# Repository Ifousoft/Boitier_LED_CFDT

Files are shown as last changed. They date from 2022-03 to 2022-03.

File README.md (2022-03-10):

# Boitier_LED_CFDT
Boitier autonome avec une LED clignotante au passage d'une personne devant un panneau d'affichage pour inciter à lire le panneau

L'objectif est la réalisation d'un petit boitier autonome fonctionnant sur piles à accrocher sur un panneau d'affichage CFDT.
Lorsqu'une personne passe devant le panneau, le capteur de présence réveille le système, la LED clignote pour indiquer qu'une nouvelle information a été affichée. Le système se rendors automatiquement pour économiser les piles.

Le système s'arrête automatiquement et se mets en sommeil après 2 jours d'utilisation, considérant que l'information n'est plus suffisamment récente.

Dans le cas d'un nouvel affichage, il suffit d'appuyer sur le bouton et le sytème rédémarre pour 2 jours.

D'après les calculs, le boitier devrait fonctionner sur pile pendant environ 1 an. Dans le cas où la pile CR2032 pour l'horloge est usée, au démarrage du système, le LED clignotera sans s'arrêter.

Le boitier comprends un arduino pour la partie processeur, une LED, orange (forcément), un bouton de réinitialisation et un mini capteur PIR pour détecter les passages des personnes.

CFDT_Boitier

PS: ayant réalisé une première version mais sans horloge, j'ai fais cette seconde version. Le code fonctionne et le schéma électronique est OK.
Néanmoins, je n'ai pas testé la réalisation du PCB ni vérifier l'impression 3D du boitier pour valider l'assemblage de tous les composants.
N'hesitez pas à effectuer des modifications si nécessaire.

Ifousoft.

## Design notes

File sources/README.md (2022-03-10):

Sources en C++ pour le boitier LED autonome
Compilation avec Platformio

Nécessite la biliothèque
lib_deps = adafruit/RTClib@^2.0.2

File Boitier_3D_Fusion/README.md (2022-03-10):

Fichier Fusion 360 et fichier STL pour l'impression 3D des deux parties du boitier, dessous et dessus.

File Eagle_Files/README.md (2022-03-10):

Fichiers Eagle pour la conception du schéma électronique et du PCB.

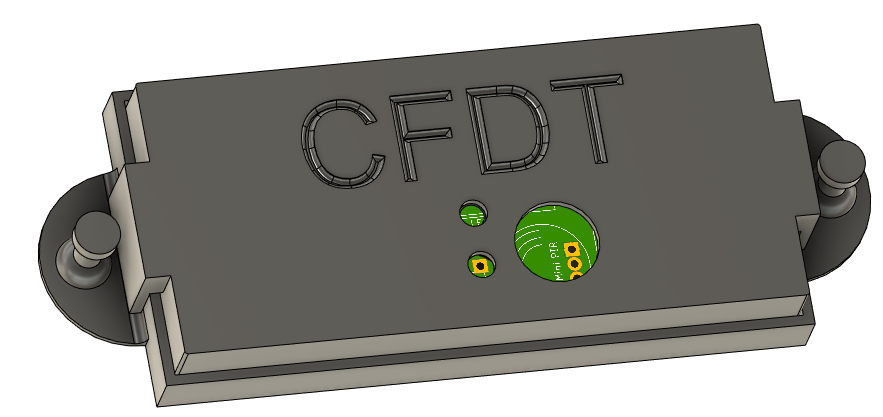
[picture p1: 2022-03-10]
Boitier_3D_Fusion/CFDT_Boitier.png

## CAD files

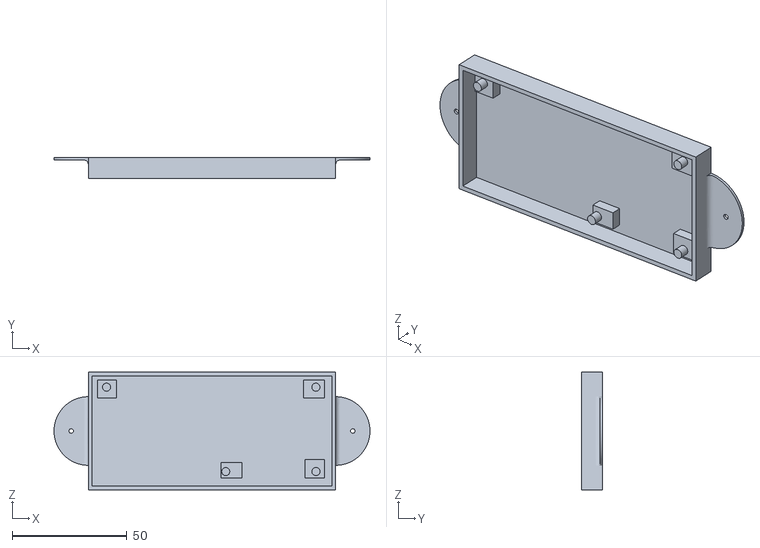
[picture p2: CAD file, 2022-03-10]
Boitier_3D_Fusion/Dessous_CFDT.stl
138.0 x 9.00 x 51.5

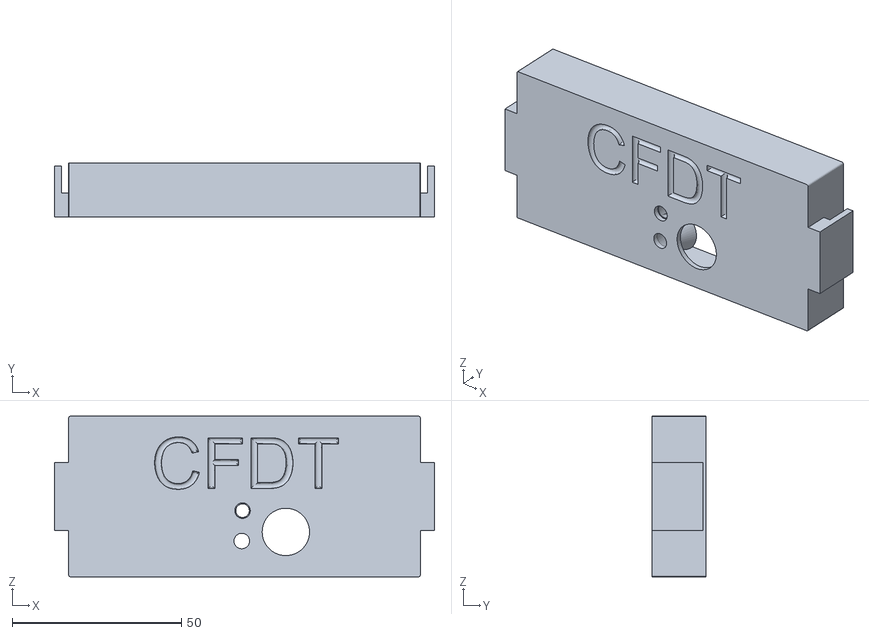
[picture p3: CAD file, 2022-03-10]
Boitier_3D_Fusion/Dessus_CFDT.stl
112.4 x 16.1 x 47.5

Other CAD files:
Boitier_3D_Fusion/Boitier_CFDT v27.f3d

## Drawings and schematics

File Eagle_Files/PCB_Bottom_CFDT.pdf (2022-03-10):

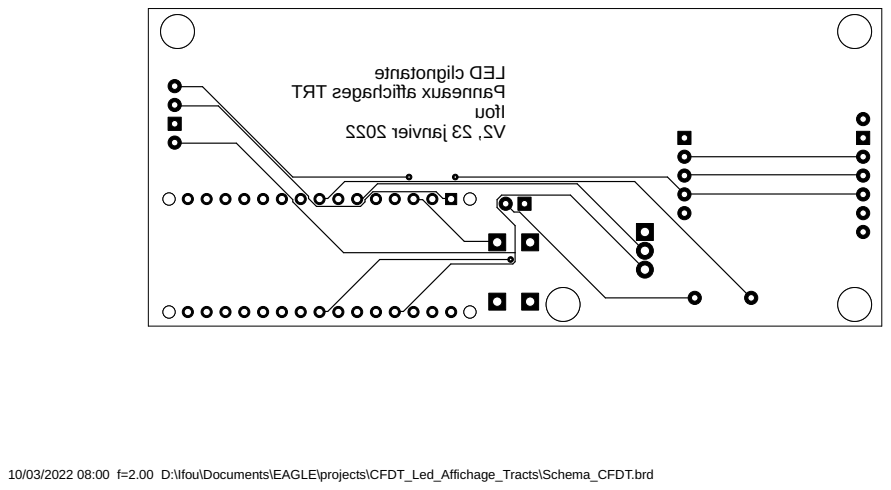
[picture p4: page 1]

et nat ongil c DEL

10/03/2022 08:00 f=2.00 D:\Ifou\Documents\EAGLE\projects\CFDT_Led_Affichage_Tracts\Schema_CFDT.brd

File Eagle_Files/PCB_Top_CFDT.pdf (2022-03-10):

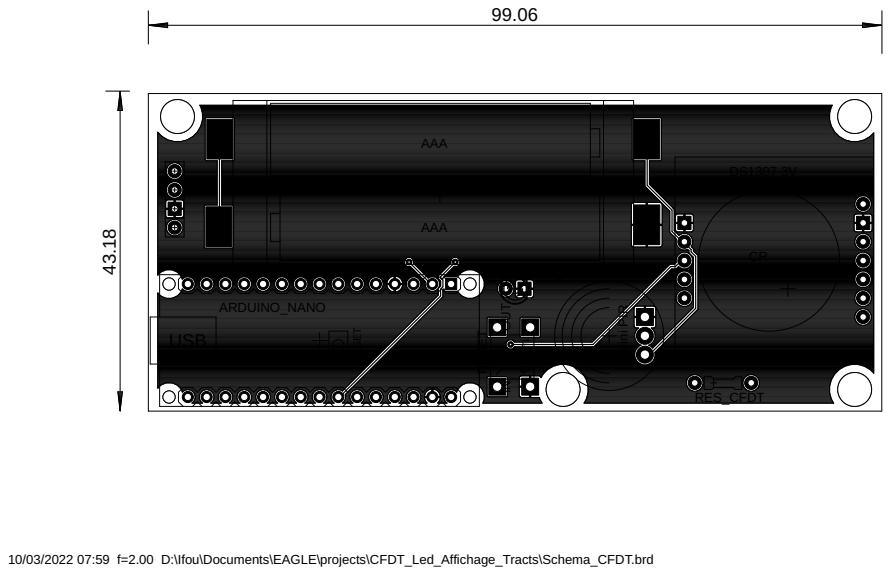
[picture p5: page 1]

10/03/2022 07:59 f=2.00 D:\Ifou\Documents\EAGLE\projects\CFDT_Led_Affichage_Tracts\Schema_CFDT.brd

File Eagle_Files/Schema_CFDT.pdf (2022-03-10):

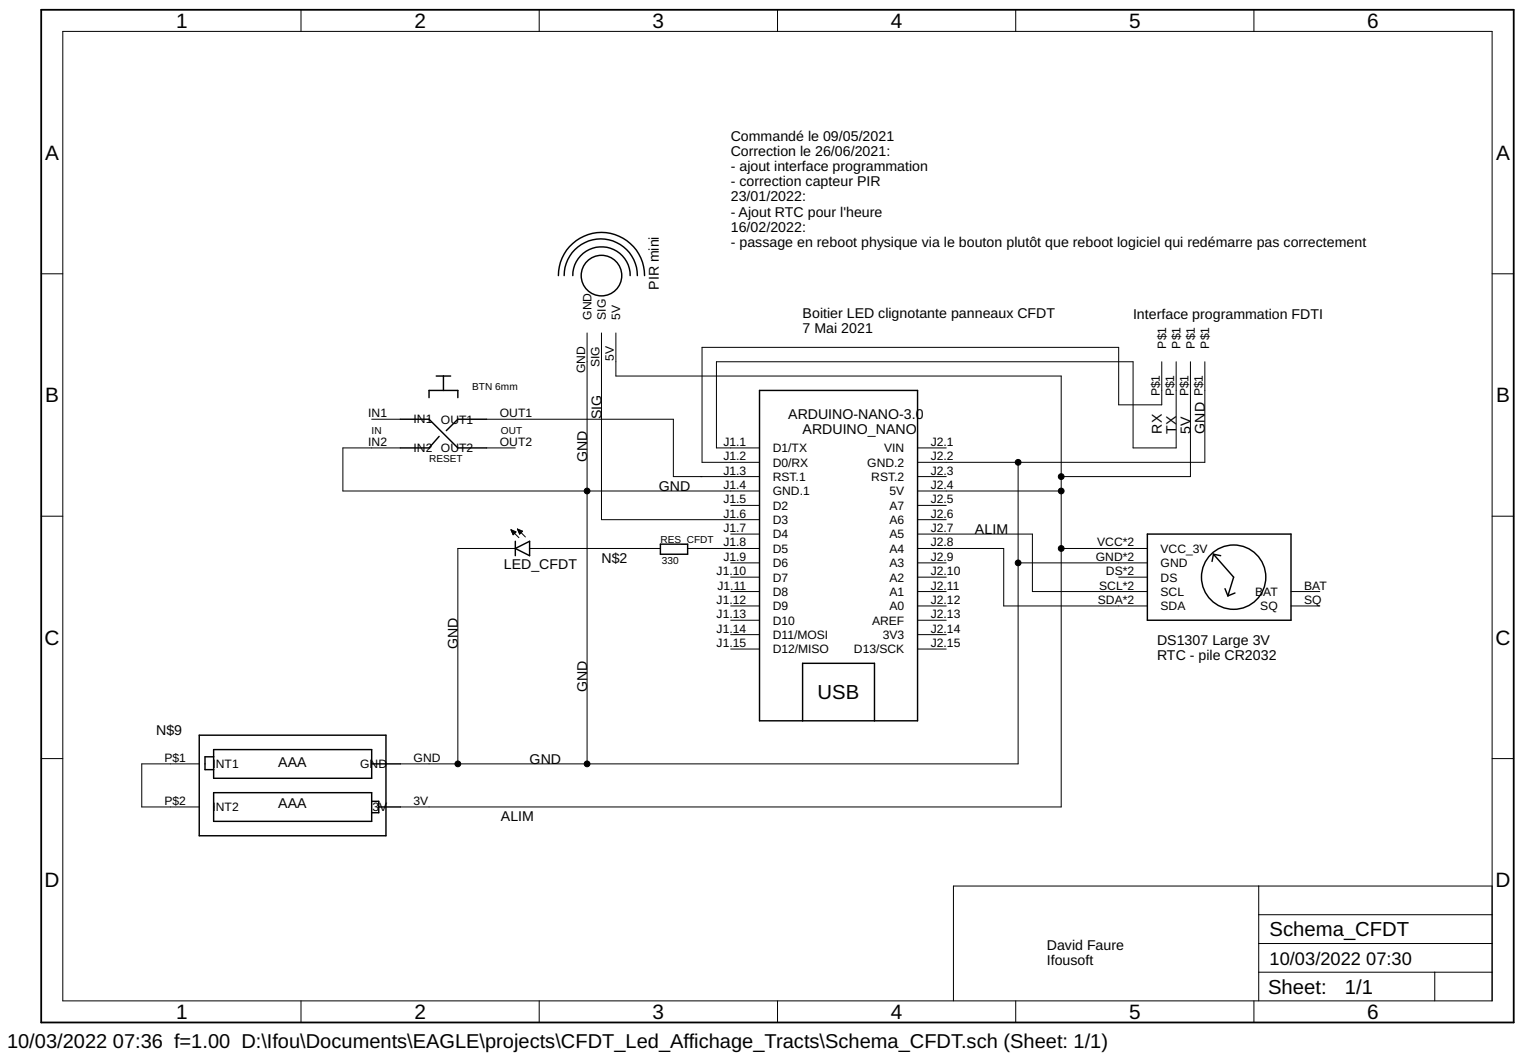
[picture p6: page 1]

Commandé le 09/05/2021
Correction le 26/06/2021: - ajout interface programmation

- correction capteur PIR
23/01/2022: - Ajout RTC pour l'heure

16/02/2022: - passage en reboot physique via le bouton plutôt que reboot logiciel qui redémarre pas correctement

Boitier LED clignotante panneaux CFDT
7 Mai 2021

David Faure Ifousoft

Sheet: 1/1

10/03/2022 07:36 f=1.00 D:\Ifou\Documents\EAGLE\projects\CFDT_Led_Affichage_Tracts\Schema_CFDT.sch (Sheet: 1/1)

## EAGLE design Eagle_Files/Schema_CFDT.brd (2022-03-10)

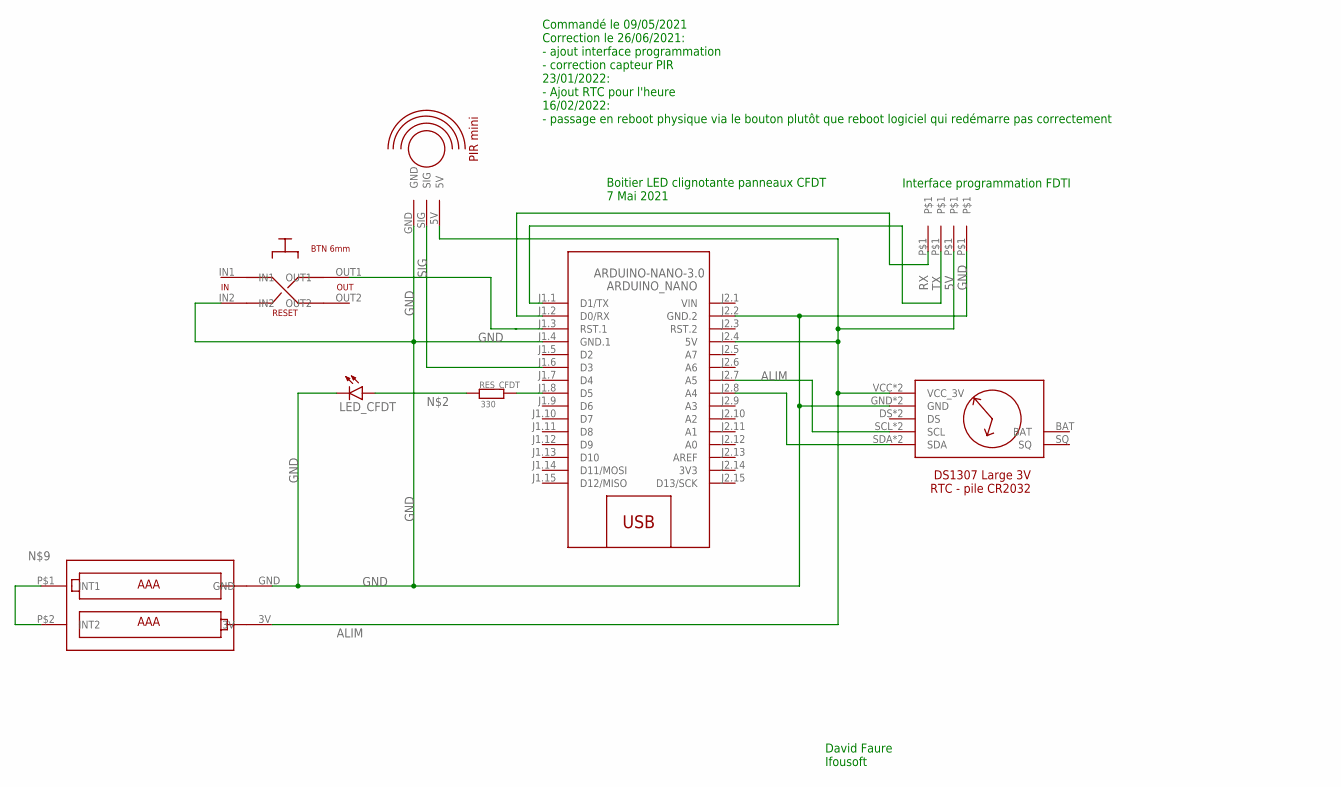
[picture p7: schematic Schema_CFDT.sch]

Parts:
5V: IFOU_PIN
ARDUINO_NANO: ARDUINO-NANO-3.0
GND: IFOU_PIN_GNDIFOU_PIN_GND2; IFOU_PIN_GND
LED_CFDT: IFOU_LED3MM; LED3MM
RESET: IFOU_SWITCH_6MM
RES_CFDT: 330; RESISTOR
RX: IFOU_PIN
TX: IFOU_PIN
U$2: IFOU_2XAAA_HOLDER
U$3: IFOU_MINI_PIR
U$4: IFOU_DS1307_RTC_3V

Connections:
3V3: ARDUINO_NANO.J2.14 (3V3)
ALIM: 5V.P$1, ARDUINO_NANO.J2.4 (5V), U$2.3V, U$3.5V, U$4.VCC (VCC_3V), U$4.VCC@2 (VCC_3V)
GND: ARDUINO_NANO.J1.4 (GND.1), ARDUINO_NANO.J2.2 (GND.2), GND.P$1, LED_CFDT.K (C), RESET.IN2, U$2.GND, U$3.GND, U$4.GND, U$4.GND@2 (GND)
unnamed: ARDUINO_NANO.J1.8 (D5), RES_CFDT.PIN2
unnamed: LED_CFDT.A, RES_CFDT.PIN1
unnamed: ARDUINO_NANO.J1.3 (RST.1), RESET.OUT1
unnamed: ARDUINO_NANO.J2.8 (A4), U$4.SDA, U$4.SDA@2 (SDA)
unnamed: ARDUINO_NANO.J2.7 (A5), U$4.SCL, U$4.SCL@2 (SCL)
unnamed: U$2.P$1 (INT1), U$2.P$2 (INT2)
RX: ARDUINO_NANO.J1.2 (D0/RX), RX.P$1
SIG: ARDUINO_NANO.J1.6 (D3), U$3.SIG
TX: ARDUINO_NANO.J1.1 (D1/TX), TX.P$1
VIN: ARDUINO_NANO.J2.1 (VIN)

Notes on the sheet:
Boitier LED clignotante panneaux CFDT 7 Mai 2021
Commandé le 09/05/2021 Correction le 26/06/2021: - ajout interface programmation - correction capteur PIR 23/01/2022: - Ajout RTC pour l'heure 16/02/2022: - passage en reboot physique via le bouton plutôt que reboot logiciel qui redémarre pas correctement
Interface programmation FDTI
David Faure Ifousoft

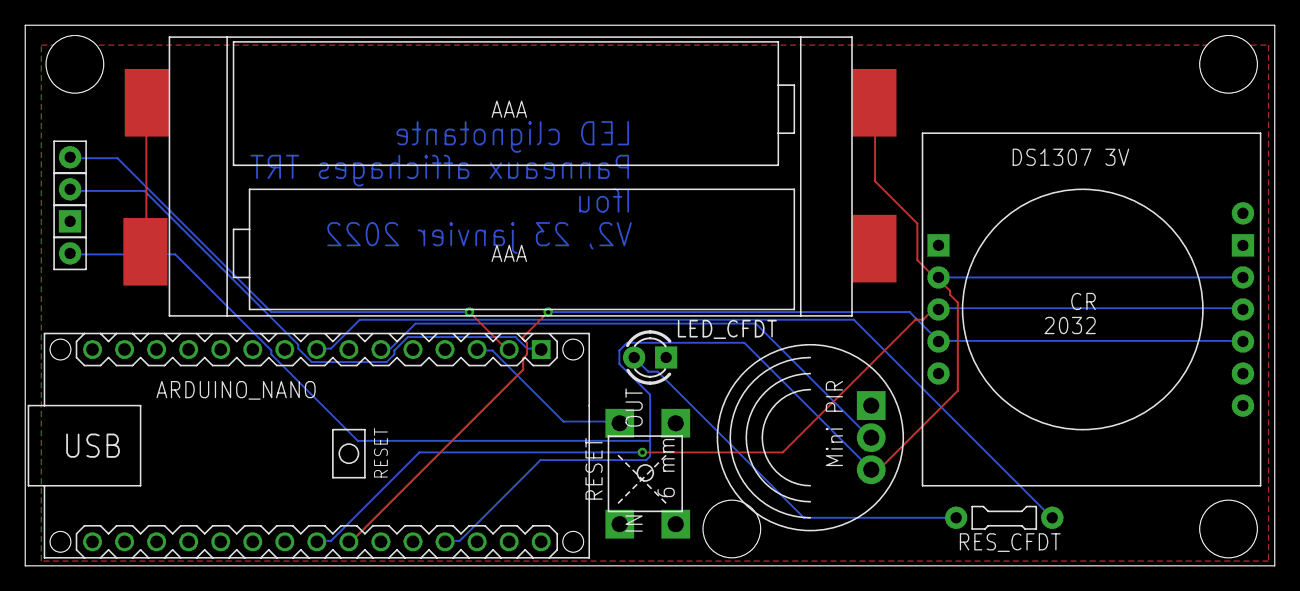
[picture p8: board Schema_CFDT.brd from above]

Board: 2 copper layers, 99.0 x 42.9 mm, 11 parts (0 on the bottom side), 11 nets.

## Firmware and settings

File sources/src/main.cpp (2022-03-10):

// LED clignotante pour tract CFDT sur panneau

// 30/04/2021 - Initialisation
// 07 mai 2021 - première version à 0,3 mA en sleep et 5 mA en fonction sur pile de 2xAAA
// 09 mai 2021 - Suppression du CH340, adptateur USB, gain de 500 microAmps - Nouvelle consommation environ 3,5 mA / 0,25 mA. Piles 2500 mA
// 26 juillet 2021 - Suppression du timer pour les 3 jours: le timer ne tourne pas en power_down. Mise en place compteur de passage + Detachement interruption pour économiser piles
// 27 septembre 2021 - Amélioration des interruptions
// 22 janvier 2022 - ajout d'un RTC pour compter la durée
// 15 février - Ajout d'un RTC 3V et non 5V...
// 16 février - le bouton connecte la masse avec la PIN reset pour redémarrer. Le reboot logiciel via le bouton rebootait bizarrement.
// 22 février - pin du bouton descendu à LOW pour envoyer GND à Reset

// A FAIRE

#include <Arduino.h>
#include <avr/sleep.h>//this AVR library contains the methods that controls the sleep modes
#include <avr/wdt.h>
#include <avr/power.h>
#include <SPI.h>
#include <Wire.h>

#include "RTClib.h"

RTC_DS1307 rtc;
// Brancher 5V sur 5V arduino
// GND - GND
// SDA - A4 arduino
// SCL - A5 Arduino

#define DEBUG   // A définir pour clignotement led interne et Serial

DateTime Time_Stop; // Calcule au boot de la date d'arrêt prévue qui sera comparée à now à chaque reveil

#define NB_MAX_JOURS    2 // Durée de fonctionnement avant endormissement total en attente de reboot

#define PIN_MOTION  3
#define PIN_BOUTON  2
#define PIN_LED     5
volatile byte Motion_Detected = LOW;
//volatile byte Bouton_Pressed = LOW;

/******************************
 * 
 * InterruptRoutinePIR
 * 
 * Appelée lorsque le détecteur de mouvement reçoit un signal
 * 
 * *********************************/
void InterruptRoutinePIR(){
    Motion_Detected = HIGH;

} /* End of InterruptRoutinePIR */

/*****************************
 * 
 * GoingToSleep
 * 
 * Endormissement perpétuel du Nano, réveil sur interruption
 * 
 * ************************************/
void Going_To_Sleep(){
#ifdef DEBUG
    Serial.println("Dodo!");//next line of code executed after the interrupt 
    Serial.flush();
    digitalWrite(LED_BUILTIN, LOW);//turning LED on
#endif
    digitalWrite(PIN_LED, LOW);//turning LED on
    delay(50); //wait a second to allow the led to be turned off before going to sleep

    sleep_cpu(); //activating sleep mode

} /* End of Goin_To_Sleep */

/*******************************************
 * 
 * setup
 * 
 * *********************************************/
void setup() {

    // turn off brown-out enable in software
    MCUCR = bit (BODS) | bit (BODSE);  // turn on brown-out enable select
    MCUCR = bit (BODS);        // this must be done within 4 clock cycles of above

    pinMode( PIN_LED, OUTPUT );

#ifdef DEBUG
    Serial.begin(9600);
    Serial.println( "Start ... ");
    pinMode( LED_BUILTIN, OUTPUT );
    digitalWrite(LED_BUILTIN, HIGH );//turning LED on
    delay( 200 );
    digitalWrite(LED_BUILTIN, LOW );//turning LED on
    delay( 200 );
    digitalWrite(LED_BUILTIN, HIGH );//turning LED on
    delay( 200 );
    digitalWrite(LED_BUILTIN, LOW );//turning LED on
    delay( 200 );
    digitalWrite(LED_BUILTIN, HIGH );//turning LED on
#endif

    digitalWrite(PIN_LED, HIGH );//turning LED on
    delay( 30 );
    digitalWrite(PIN_LED, LOW );//turning LED on
    delay( 30 );
    digitalWrite(PIN_LED, HIGH );//turning LED on
    delay( 30 );
    digitalWrite(PIN_LED, LOW );//turning LED on
    delay( 30 );
    digitalWrite(PIN_LED, HIGH );//turning LED on

    pinMode(PIN_MOTION, INPUT_PULLUP);
    pinMode(PIN_BOUTON, OUTPUT);
    digitalWrite( PIN_BOUTON, LOW ); // Mise à la masse du bouton pour envoyer GND à RESET

    //Bouton_Pressed = LOW;
    Motion_Detected = LOW;

    attachInterrupt(digitalPinToInterrupt( PIN_MOTION), InterruptRoutinePIR, HIGH);  //attaching a interrupt to pin d3 (Interruption 1 )

    // Sleep
    clock_prescale_set(clock_div_8); // division par huit fréquence et SLEEP_MODE_PWR_DOWN 1,33 et 6,8 mA (Sleep et fonction) / 0,5 mA
    sleep_enable(); //Enabling sleep mode

    set_sleep_mode(SLEEP_MODE_PWR_DOWN);    //Setting the sleep mode, in our case full sleep

    // RTC managment
    if (! rtc.begin()) {
#ifdef DEBUG
        Serial.println("Couldn't find RTC");
        Serial.flush();
#endif
        while (1)
        {
            // Clignotement de la led
            digitalWrite(PIN_LED, HIGH ); //turning LED on
            delay( 100 );
            digitalWrite(PIN_LED, LOW ); //turning LED on
            delay( 100 );
        }
    } 

    if (! rtc.isrunning()) {
#ifdef DEBUG
        Serial.println("RTC is NOT running, let's set the time!");
#endif
        // When time needs to be set on a new device, or after a power loss, the
        // following line sets the RTC to the date & time this sketch was compiled
        rtc.adjust(DateTime(F(__DATE__), F(__TIME__)));
        // This line sets the RTC with an explicit date & time, for example to set
        // January 21, 2014 at 3am you would call:
        // rtc.adjust(DateTime(2014, 1, 21, 3, 0, 0));
    }

    DateTime now = rtc.now(); // Heure actuelle

    // Prévoir quand s'arrêter
    Time_Stop = now + TimeSpan(NB_MAX_JOURS, 0, 0, 0); // Jours, heures, minutes, secondes

} /* End of setup */

/********************************************
 * 
 * loop
 * 
 * ******************************************/
void loop()
{
    Going_To_Sleep();

    DateTime now = rtc.now(); // Heure de reveil

#ifdef DEBUG
    Serial.println("just woke up!");//next line of code executed after the interrupt 
    digitalWrite(LED_BUILTIN, HIGH);//turning LED on

    Serial.print(now.year(), DEC);
    Serial.print('/');
    Serial.print(now.month(), DEC);
    Serial.print('/');
    Serial.print(now.day(), DEC);
    //Serial.print(" (");
    //Serial.print(daysOfTheWeek[now.dayOfTheWeek()]);
    //Serial.print(") ");
    Serial.print(now.hour(), DEC);
    Serial.print(':');
    Serial.print(now.minute(), DEC);
    Serial.print(':');
    Serial.print(now.second(), DEC);
    Serial.println();

#endif

    if( Motion_Detected == HIGH )
    {
        Motion_Detected = LOW;

        // Si on a vu passer quelqu'un devant la LED
        for( byte i = 0 ; i < 5 ; i ++)
        {
            digitalWrite(PIN_LED, HIGH);    //turning LED on
            delay( 10 );
            digitalWrite(PIN_LED, LOW);    //turning LED on
            delay( 10 );

        } /* End of for */

    } /* End of if */

#ifdef DEBUG
    Serial.println( "Minutes:");
    Serial.println( Time_Stop.minute() );
    Serial.println( "Heure: ");
    Serial.println( now.minute());
#endif

    if( now > Time_Stop )
    {
#ifdef DEBUG
        Serial.println( "------------ STOP ----------- ");
#endif
        detachInterrupt( digitalPinToInterrupt( PIN_MOTION) );
    } /* End of if */

} /* End of loop */

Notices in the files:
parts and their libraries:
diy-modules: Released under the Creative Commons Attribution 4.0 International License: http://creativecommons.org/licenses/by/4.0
